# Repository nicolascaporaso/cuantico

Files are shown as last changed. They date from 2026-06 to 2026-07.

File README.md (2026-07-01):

# Cuántico

Cuántico (https://youtu.be/RmWtU8Pogws)

> 🎬 Video de la build: [youtu.be/RmWtU8Pogws](https://youtu.be/RmWtU8Pogws)

Cuántico es un asistente de voz con hardware, personalidad configurable y herramientas reales. Corre en una Raspberry Pi, escucha con wake word, habla por ElevenLabs, razona con OpenRouter y controla luces, música, calendario, YouTube, timers, memoria persistente y audio Bluetooth.

No está pensado para sonar neutro. Está pensado para tener carácter, cambiar de actitud con LEDs y sentirse más criatura de taller que producto pulido.

## Estado actual

- Backend LLM: OpenRouter, no Gemini.
- STT: Deepgram.
- TTS: ElevenLabs.
- Wake word: openWakeWord.
- Salida principal: I2S/VoiceHAT con fallback y soporte para parlantes Bluetooth.
- Personalidad, emociones y luces: perfiles editables en JSON.
- Timers, estado Bluetooth, recuerdos y tokens: persistentes en `state/`.

## Qué hace hoy

- Conversación por voz con wake word.
- Seguimiento sin wake word durante unos segundos después de cada respuesta.
- Búsqueda web integrada para datos actuales.
- Function calling local con tools Python.
- Control de luces Govee: on/off, color y brillo.
- Spotify: canción, playlist por vibe, play/pause, siguiente, anterior, volumen.
- Timers y alarmas persistentes, incluyendo lenguaje natural:
  - `en 30 segundos`
  - `en 5 minutos`
  - `en 2 horas`
  - `mañana a las 7am`
  - `a las 18:30`
- Google Calendar: ver hoy, ver semana, crear eventos.
- YouTube Analytics: métricas y últimos videos.
- Memoria persistente con SQLite.
- Modo llamada por altavoz/micro físico.
- Perfiles de personalidad y reactor LED configurables.
- Audio Bluetooth por voz:
  - buscar
  - listar
  - conectar
  - desconectar
  - consultar cuál está activo
  - volver al altavoz integrado

## Arquitectura

```text
Wake word / VAD / audio
    micro.py
        ↓
Deepgram STT
        ↓
main.py
  - loop principal
  - tools
  - memoria
  - timers
  - modo llamada
        ↓
openrouter_client.py
  - chat
  - tool calling
  - web search
        ↓
altavoz.py
  - ElevenLabs TTS
  - ruta I2S o Bluetooth
        ↓
luces.py
  - reactor LED según estado/emoción
```

Servicios y módulos auxiliares:

- `govee.py`: Developer API v1
- `spotify.py`: Spotify Connect / Raspotify
- `calendario.py`: Google Calendar
- `youtube_stats.py`: YouTube Data + Analytics
- `recuerdos.py`: SQLite
- `timers.py`: scheduler persistente
- `bluetooth_audio.py`: BlueZ + BlueALSA
- `cuantico_profiles.py` + `cuantico_profiles.json`: prompts, emociones y luces

## Hardware

### BOM base

| Componente | Modelo / idea | Notas |
|---|---|---|
| SBC | Raspberry Pi Zero 2 W | La build original apunta a esta. |
| microSD | 16–32 GB clase 10 | Mejor si es decente; Cuántico genera logs y estado persistente. |
| Micrófono | INMP441 I2S | Captura principal. |
| Amplificador | MAX98357A I2S | Salida mono al parlante. |
| Parlante | 3W 4Ω | Conectado al MAX98357A. |
| LEDs | NeoPixel / WS2812B | Reactor visual. |
| Bluetooth | Integrado en la Pi | Para parlantes BT opcionales. |

### Cableado usado en el proyecto

> Los números son pines físicos del header, no BCM.

#### INMP441

| Pin | Pi | Función |
|---|---|---|
| VDD | 1 | 3.3V |
| GND | 39 | GND |
| L/R | a GND | Canal izquierdo |
| SCK | 12 | BCLK |
| WS | 35 | LRCLK |
| SD | 38 | Datos |

#### MAX98357A

| Pin | Pi | Función |
|---|---|---|
| VIN / VDD | 4 | 5V |
| GND | 34 | GND |
| BCLK | 12 | I2S clock |
| LRC | 35 | I2S word select |
| DIN | 40 | Datos hacia el ampli |
| SD | 36 | Mute |

#### NeoPixel

| Pin | Pi |
|---|---|
| 5V | 2 |
| GND | 6 |
| DIN | 32 |

### Carcasa

El repo incluye piezas en `hardware/` para impresión 3D y CNC. Si solo te interesa replicar software, puedes ignorarlo.

## Dependencias del sistema

En Raspberry Pi OS Lite:

```bash
sudo apt update
sudo apt install -y \
  git python3-venv python3-pip \
  sox libsox-fmt-mp3 alsa-utils tmux \
  mpv yt-dlp \
  bluez bluez-alsa-utils
```

Spotify Connect opcional:

```bash
curl -sSL https://dtcooper.github.io/raspotify/install.sh | sh
```

### Overlay de audio recomendado

En `/boot/firmware/config.txt` o `/boot/config.txt`:

```ini
dtparam=i2s=on
dtoverlay=googlevoicehat-soundcard
dtparam=audio=off
```

Reinicia:

```bash
sudo reboot
```

Comprueba:

```bash
arecord -l
aplay -l
```

## Instalación

### 1. Clona el repo

```bash
git clone <tu-repo> ~/cuantico
cd ~/cuantico
```

### 2. Crea el entorno virtual

```bash
python3 -m venv .venv
source .venv/bin/activate
pip install -r requirements.txt
```

### 3. Crea `.env`

```bash
cp .env.example .env
```

### 4. Rellena variables mínimas

Variables imprescindibles para arrancar:

- `OPENROUTER_API_KEY`
- `ELEVENLABS_API_KEY`
- `DEEPGRAM_API_KEY`
- `GOVEE_API_KEY`
- `WAKE_MODEL_PATH`

Variables muy recomendables:

- `CUANTICO_PROFILE`
- `CUANTICO_TIMEZONE`
- `USER_SHORT_NAME`
- `USER_FULL_NAME`

Variables opcionales:

- Spotify
- Google Calendar / YouTube
- Bluetooth
- `OPENROUTER_HTTP_REFERER`

## Variables de entorno

### Identidad y perfil

```env
USER_SHORT_NAME=Nico
USER_FULL_NAME=Nicolas
CUANTICO_PROFILE=argentino
CUANTICO_TIMEZONE=America/Argentina/Buenos_Aires
```

### LLM

```env
OPENROUTER_API_KEY=
OPENROUTER_MODEL=openai/gpt-4o-mini
OPENROUTER_CALL_MODEL=openai/gpt-4o-mini
OPENROUTER_HTTP_REFERER=
```

### Audio

```env
ELEVENLABS_API_KEY=
ELEVENLABS_VOICE_ID=JBFqnCBsd6RMkjVDRZzb
ALSA_PLAYBACK_DEVICE=plughw:0,0
BLUETOOTH_AUTO_ROUTE=true
BLUETOOTH_AUDIO_PROFILE=a2dp
BLUETOOTH_SCAN_SECONDS=8
```

### STT y wake word

```env
DEEPGRAM_API_KEY=
WAKE_MODEL_PATH=/home/nicolas/cuantico/cuantico.onnx
```

También puedes usar un modelo preentrenado de openWakeWord, por ejemplo `hey_jarvis`, si apuntas la ruta correcta dentro de tu entorno.

### Govee

```env
GOVEE_API_KEY=
```

### Spotify

```env
SPOTIFY_CLIENT_ID=
SPOTIFY_CLIENT_SECRET=
SPOTIFY_REDIRECT_URI=http://127.0.0.1:8888/callback
MUSIC_BACKEND_DEFAULT=spotify
YT_DLP_COMMAND=yt-dlp
MPV_COMMAND=mpv
YOUTUBE_AUDIO_SEARCH_LIMIT=5
YOUTUBE_PLAYLIST_SEARCH_LIMIT=8
```

### Google / YouTube

```env
GOOGLE_CLIENT_SECRETS_PATH=state/google_client.json
GOOGLE_TOKEN_PATH=state/google_token.json
YOUTUBE_CHANNEL_ID=
```

## Wake word

Cuántico usa `openwakeword`. En el repo hay un modelo `cuantico.onnx`, pero también puedes usar uno preentrenado o entrenar el tuyo.

Ejemplo:

```env
WAKE_MODEL_PATH=/home/nicolas/cuantico/cuantico.onnx
```

## Primer arranque manual

En la Raspberry:

```bash
sudo .venv/bin/python3 src/main.py
```

> En la Pi el `sudo` es importante por NeoPixel y acceso a hardware. En un entorno sin LEDs físicos no siempre hace falta.

## Spotify

`spotify.py` usa `spotipy` y busca un dispositivo cuyo nombre contenga `raspotify` o `cuantico`.

Flujo real:

- si Spotify no está configurado, se desactiva solo
- si está configurado, intenta descubrir el dispositivo Connect
- si no lo encuentra, deja warning en consola

Primera autorización:

- Spotipy usa flujo OAuth con `open_browser=False`
- en consola te mostrará una URL
- debes abrirla, autorizar y pegar la URL final redirigida

Se guarda en:

- `.spotify_cache`

## Musica Por YouTube

Cuántico también puede reproducir música sin Premium usando:

- `yt-dlp` para buscar y resolver audio
- `mpv` para reproducir y controlar play/pause/siguiente/anterior/volumen

Este backend usa la misma ruta de audio activa que el TTS:

- I2S / VoiceHAT local
- parlante Bluetooth si está conectado y activo

Comportamiento actual:

- antes de arrancar la reproducción, Cuántico prepara el tema y le pide a `mpv` que espere con cache hasta juntar bastante buffer
- para YouTube intenta acercarse a "medio tema" cacheado, con límites razonables para que la espera no se vuelva eterna
- si detecta que esa preparación va a tardar un poco, agrega una frase corta con un dato del tema o del canal mientras termina de cargar
- si la carga pinta rápida, no mete ese comentario extra

Estado persistente:

- `state/music_backend.json`

Variables útiles:

```env
MUSIC_BACKEND_DEFAULT=spotify
YT_DLP_COMMAND=yt-dlp
MPV_COMMAND=mpv
YOUTUBE_AUDIO_SEARCH_LIMIT=5
YOUTUBE_PLAYLIST_SEARCH_LIMIT=8
```

Frases útiles:

- `usá youtube para la música`
- `usá spotify para la música`
- `qué sistema de música estás usando`
- `poné Soda Stereo por youtube`
- `poneme algo chill por youtube`

Notas reales:

- si el backend activo es `youtube`, los comandos generales de música salen por `yt-dlp + mpv`
- si el backend activo es `spotify`, siguen saliendo por Spotify Connect / Raspotify
- cambiar el backend por voz actualiza la preferencia persistente para los próximos pedidos

## Google Calendar y YouTube

`calendario.py` y `youtube_stats.py` comparten el mismo token OAuth.

Primera autorización:

1. Crea un OAuth Client tipo Desktop en Google Cloud.
2. Guarda el JSON como `state/google_client.json`.
3. Ejecuta una vez en una máquina con navegador.
4. Se generará `state/google_token.json`.
5. Copia ese token a la Pi.

Si cambias scopes:

- borra `state/google_token.json`
- vuelve a autorizar

## Timers y alarmas

Cuántico soporta dos tipos:

- timer relativo
- alarma absoluta

Internamente todo se persiste en:

- `state/timers.json`

El scheduler:

- sobrevive a reinicios
- carga timers existentes al arrancar
- dispara callbacks de voz al vencer
- si algo venció mientras estaba apagado, lo levanta al iniciar

Ejemplos de frases soportadas:

- `avisame en 30 segundos`
- `poné una alarma en 5 minutos`
- `avisame en 2 horas`
- `poné una alarma mañana a las 7am`
- `poné una alarma a las 18:30`

## Memoria persistente

La memoria no es historial de chat. Son hechos persistentes.

Se guarda en:

- `state/recuerdos.db`

Sirve para:

- gustos
- personas importantes
- proyectos
- datos estables del usuario

No debería usarse para:

- secretos
- contraseñas
- datos de tarjeta
- cosas efímeras que dejan de ser verdad enseguida

## Audio

### Ruta local

La reproducción local usa:

- `sox` para filtrar/normalizar
- `aplay` para sacar el audio
- GPIO16 para mutear/desmutear el ampli de la VoiceHAT

### Sonido de arranque

Si existe `test.wav` en la raíz del repo, Cuántico puede reproducirlo al arrancar.

### Bluetooth

El control Bluetooth está en `src/bluetooth_audio.py` y usa:

- `bluetoothctl`
- BlueZ
- BlueALSA

Estado persistente:

- `state/bluetooth_audio.json`

Funciones soportadas:

- buscar dispositivos
- listar dispositivos
- conectar uno por nombre o MAC
- desconectar uno concreto
- consultar cuál está activo
- volver al altavoz integrado
- recordar el parlante Bluetooth preferido

Frases útiles:

- `buscá parlantes bluetooth`
- `listá los parlantes bluetooth`
- `conectá el JBL Flip`
- `desconectá el JBL Flip`
- `qué parlante bluetooth está conectado`
- `volvé al altavoz integrado`

Si el parlante BT no está conectado en el momento de hablar:

- Cuántico vuelve al `ALSA_PLAYBACK_DEVICE` local

## Reactor LED y emociones

`luces.py` no tiene efectos fijos hardcodeados por personalidad. El reactor se alimenta desde `cuantico_profiles.json`.

Estados base del sistema:

- `esperando`
- `escuchando`
- `pensando`
- `apagado`

Estados emocionales:

- dependen del perfil activo
- se detectan por triggers en la respuesta de Cuántico
- controlan color, patrón y velocidad

Efectos soportados:

- `pulse`
- `spinner`
- `flicker`
- `rainbow`
- `blink`
- `alternate`
- `off`

## Perfiles, prompts y personalidad

Los prompts ya no viven en `main.py`. Viven en:

- `src/cuantico_profiles.json`
- `src/cuantico_profiles.py`

Un perfil define:

- `label`
- `main_prompt`
- `call_prompt`
- `default_emotion`
- `emotion_rules`
- `light_states`
- alias de estados si hace falta

Perfiles incluidos hoy:

- `argentino`
- `espanol`
- `tanguero`

Selección:

```env
CUANTICO_PROFILE=tanguero
```

Para crear uno nuevo:

1. Duplica un perfil en `src/cuantico_profiles.json`
2. Ponle una nueva clave
3. Cambia `CUANTICO_PROFILE`
4. Reinicia Cuántico

## Modo llamada

`llamada.py` monta un modo especial para hablar con otra persona por teléfono usando el móvil en altavoz al lado del dispositivo.

Flujo:

1. El usuario activa la intención de llamada.
2. Cuántico responde normal.
3. Al terminar de hablar entra en modo llamada.
4. Usa un prompt específico, más profesional.
5. Escucha y responde por streaming.
6. Sale por:
   - marcador `[FIN_LLAMADA]`
   - silencio largo
   - timeout global
   - orden explícita de colgar

## Servicio systemd

El repo incluye:

- `cuantico.service`

Instalación:

```bash
sudo cp ~/cuantico/cuantico.service /etc/systemd/system/cuantico.service
sudo systemctl daemon-reload
sudo systemctl enable --now cuantico
```

Comandos útiles:

```bash
systemctl status cuantico
journalctl -u cuantico -f
sudo systemctl restart cuantico
sudo systemctl stop cuantico
```

El servicio actual:

- arranca tras red, sonido y Bluetooth
- corre como `root`
- usa `/home/nicolas/cuantico` como ejemplo de ruta

Ajústalo si tu usuario o ruta son distintos.

## Logs y depuración

Además de `journalctl`, Cuántico escribe trazas estructuradas en:

- `state/unexpected-process-exit.log`

Se instrumentan, entre otras cosas:

- arranque y cierre
- excepciones no manejadas
- excepciones de threads
- señales
- wake word
- Deepgram
- OpenRouter
- TTS
- timers
- callbacks de alarma
- Bluetooth

Archivos de ayuda incluidos:

- `debug-unexpected-process-exit.md`
- `debug-timer-alarm-exit.md`

## Estado persistente generado

Durante el uso se crean o actualizan estos archivos:

- `state/recuerdos.db`
- `state/timers.json`
- `state/bluetooth_audio.json`
- `state/music_backend.json`
- `state/google_client.json`
- `state/google_token.json`
- `state/unexpected-process-exit.log`

Y también:

- `.spotify_cache`

## Estructura del repo

```text
.
├── README.md
├── LICENSE
├── requirements.txt
├── .env.example
├── cuantico.service
├── cuantico.onnx
├── cuantico.onnx.data
├── debug-timer-alarm-exit.md
├── debug-unexpected-process-exit.md
├── hardware/
└── src/
    ├── altavoz.py
    ├── bluetooth_audio.py
    ├── calendario.py
    ├── config.py
    ├── cuantico_profiles.json
    ├── cuantico_profiles.py
    ├── govee.py
    ├── llamada.py
    ├── luces.py
    ├── main.py
    ├── music_router.py
    ├── music_youtube.py
    ├── micro.py
    ├── openrouter_client.py
    ├── recuerdos.py
    ├── spotify.py
    ├── timers.py
    └── youtube_stats.py
```

## Troubleshooting

### No suena la voz pero `test.wav` sí

Te falta casi seguro:

```bash
sudo apt install -y libsox-fmt-mp3
```

### El micro no abre a 16 kHz

Es normal en algunos devices I2S/VoiceHAT. `micro.py` ya hace fallback a 48 kHz y remuestrea a 16 kHz.

### Spotify no aparece

- verifica que `raspotify` esté corriendo
- revisa el nombre del dispositivo Connect
- ajusta `DEVICE_HINTS` en `src/spotify.py` si hace falta

### YouTube no reproduce musica

- instala `mpv` y `yt-dlp`
- revisa que `YT_DLP_COMMAND` y `MPV_COMMAND` apunten a binarios válidos
- si usás Bluetooth, verifica que `state/bluetooth_audio.json` apunte al parlante correcto
- si `spotify` te da `403`, cambia temporalmente el backend con `usá youtube para la música`

### Govee da 401 o no controla nada

- revisa tu API key
- no todos los modelos sirven con la Developer API v1

### Wake word responde mal

Revisa en `src/micro.py`:

- `WAKE_THRESHOLD`
- `GANANCIA_MIC`

Y mira los logs `score wake=...`.

### Se cayó la Pi o perdió SSH

Cuando vuelva:

```bash
journalctl -b -1 -n 200 --no-pager
journalctl -k -b -1 -n 200 --no-pager
dmesg -T | tail -n 120
```

### La base SQLite quedó readonly

Si corriste Cuántico con `sudo`, puede que `state/` quede propiedad de `root`.

Corrígelo si quieres inspeccionarla manualmente:

```bash
sudo chown -R nicolas:nicolas state
```

### Bluetooth no conecta

Comprueba:

```bash
sudo systemctl status bluetooth
bluetoothctl devices
bluetoothctl info <MAC>
```

Y asegúrate de tener:

```bash
sudo apt install -y bluez bluez-alsa-utils
```

## Stack

- LLM gateway: [OpenRouter](https://openrouter.ai/)
- STT: [Deepgram](https://deepgram.com/)
- TTS: [ElevenLabs](https://elevenlabs.io/)
- Wake word: [openWakeWord](https://github.com/dscripka/openWakeWord)
- VAD: [webrtcvad](https://github.com/wiseman/py-webrtcvad)
- Spotify: [spotipy](https://spotipy.readthedocs.io/)
- Google APIs: Calendar + YouTube
- LEDs: NeoPixel / `rpi_ws281x`

## Licencia

Ver `LICENSE`.

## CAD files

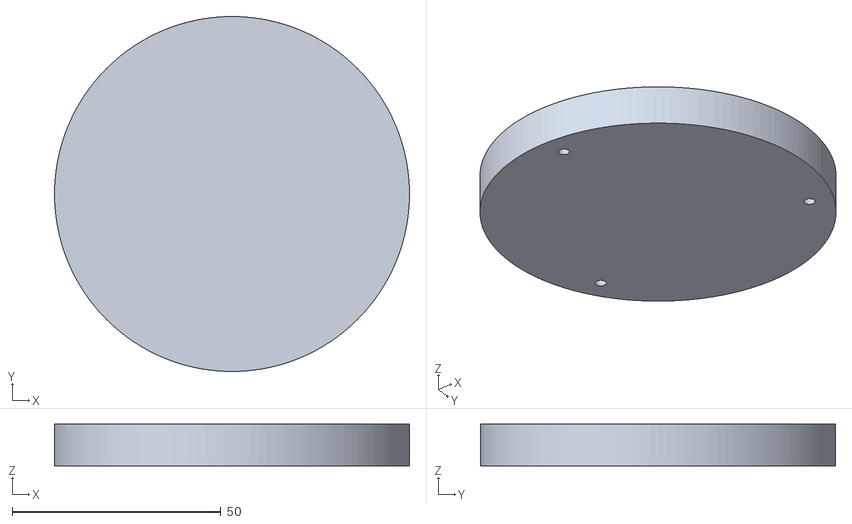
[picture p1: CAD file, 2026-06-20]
hardware/3d printing/Tapa_Cuantico.stl
85.0 x 85.0 x 10.0

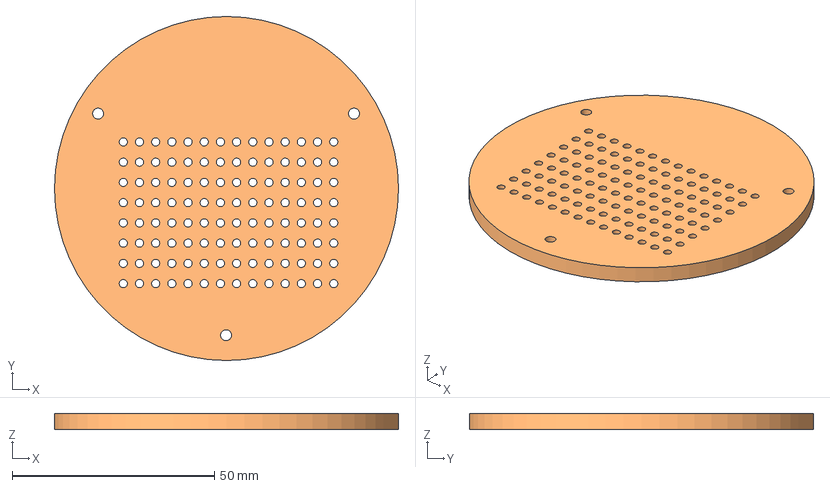
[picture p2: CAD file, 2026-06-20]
hardware/CNC/Intermedio.stp
85.0 x 85.0 x 4.00 mm

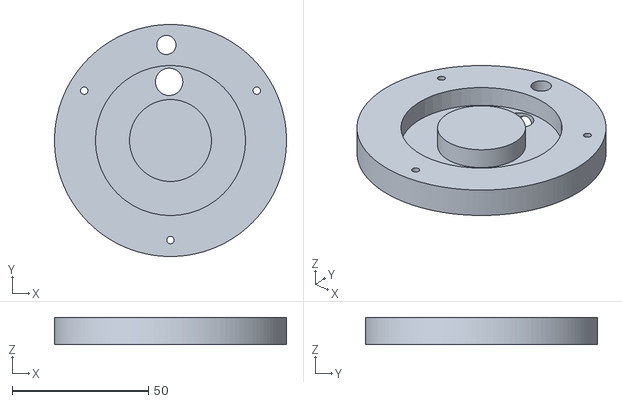
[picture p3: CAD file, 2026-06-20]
hardware/3d printing/Base_Cuantico.stl
85.0 x 85.0 x 10.00

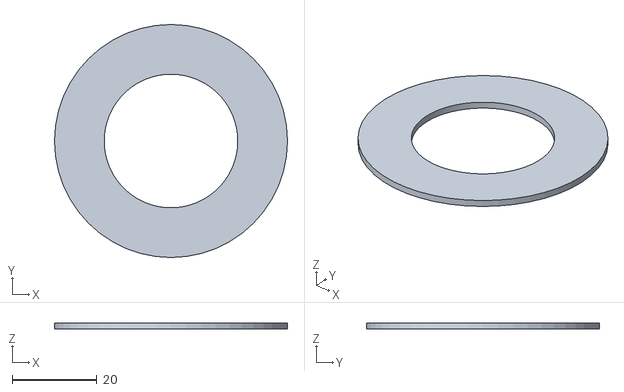
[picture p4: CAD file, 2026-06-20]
hardware/3d printing/Luces_Tapa.stl
55.0 x 55.0 x 1.50

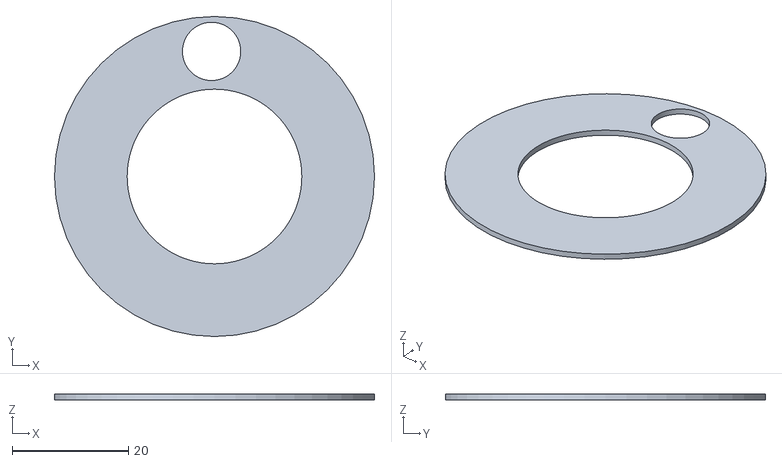
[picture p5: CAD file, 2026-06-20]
hardware/3d printing/Luces_Base.stl
55.0 x 55.0 x 1.00

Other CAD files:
hardware/CNC/Tapa.stp
hardware/CNC/Base.stp
hardware/3d printing/Intermedio_Cuantico.stl

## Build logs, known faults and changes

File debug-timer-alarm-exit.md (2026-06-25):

[OPEN] timer-alarm-exit

## Objetivo
- Corregir el manejo de timers/alarmas relativas y absolutas.
- Ajustar la zona horaria interna a America/Argentina/Buenos_Aires.
- Agregar logs y manejo de excepciones alrededor del scheduler/callback para capturar fallas reales cuando vence una alarma.

## Sintomas
- Pedidos como "en 60 segundos" a veces terminan yendo por `crear_alarma_hora`.
- La hora interna de referencia sigue orientada a Europe/Madrid.
- El usuario reporta cierre del proceso cuando una alarma vence y habla.

## Hipotesis
1. El modelo elige la tool equivocada por docstrings/prompt insuficientemente precisos para diferenciar duracion relativa vs hora absoluta.
2. El scheduler dispara bien, pero el callback de alarma rompe el proceso durante `_hablar()` o TTS.
3. La zona horaria usada por Cuantico deforma la interpretacion de horas y empeora la seleccion de tools.
4. `timers.py` carece de instrumentacion suficiente y por eso el error real del callback queda oculto.
5. La configuracion del servicio systemd no es la causa principal, aunque tiene un warning aparte.

## Evidencia Actual
- Logs muestran que "Poné una alarma para dentro de 60 segundos" llamo `crear_alarma_hora("02:34")` en vez de `crear_temporizador(...)`.
- `timers.py` programa alarmas HH:MM para hoy o manana si ya paso.
- No hay aun evidencia completa del cierre al vencer una alarma porque faltan logs explicitos en `timers.py`.

## Instrumentacion Aplicada
- `timers.py` ahora emite:
  - `timers-init`
  - `timer-created`
  - `alarm-created`
  - `timer-fired`
  - `timer-callback-start`
  - `timer-callback-end`
  - `timer-callback-error`
- `main.py` ahora emite:
  - `alarm-callback-enter`
  - `alarm-callback-exit`
  - `alarm-callback-error`

## Fix Aplicado
1. Se agrego `programar_aviso(cuando, etiqueta)` como tool unificada para lenguaje natural:
   - segundos
   - minutos
   - horas
   - dias
   - hoy/manana a HH:MM
   - am/pm
2. Se reforzaron docstrings y prompt para preferir esa tool en pedidos temporales.
3. La zona horaria interna se cambio a `America/Argentina/Buenos_Aires`.
4. `timers.py` ahora calcula alarmas absolutas con hora local de Buenos Aires.
5. `calendario.py`, `recuerdos.py` y referencias temporales del prompt usan la nueva zona horaria.
6. `cuantico.service` se corrigio para usar la ruta real y mover `StartLimitIntervalSec/StartLimitBurst` a `[Unit]`.

## Plan
1. Instrumentar `timers.py` y el callback de alarma con logs y excepciones controladas.
2. Verificar como se construye el contexto temporal del modelo.
3. Implementar soporte robusto para segundos/minutos/horas relativos y horas absolutas.
4. Ajustar zona horaria de referencia a Buenos Aires.
5. Validar con compilacion y dejar guia de prueba.

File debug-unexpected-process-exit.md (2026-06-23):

[OPEN] Debug Session: unexpected-process-exit

## Resumen
- Sintoma: Cuantico "se cuelga", pero en realidad el proceso Python se cierra mientras la Raspberry sigue encendida.
- Objetivo: recolectar evidencia de runtime para identificar por que el proceso termina.

## Hipotesis Iniciales
1. Una excepcion no capturada fuera del loop principal termina el proceso.
2. Un subproceso de audio/TTS/STT falla y arrastra el cierre del proceso.
3. Un fallo de red o I/O queda oculto y dispara una salida fatal.
4. Un hilo secundario (luces, timers, micro) lanza una excepcion relevante.
5. Existe una ruta de salida no intencional en el flujo principal.

## Plan
1. Agregar instrumentacion de arranque, ciclo principal y cierres.
2. Agregar trazas en puntos criticos: audio, micro, timers, modo llamada, OpenRouter.
3. Reproducir la caida y observar el ultimo bloque de logs.
4. Confirmar o descartar hipotesis con evidencia.
5. Aplicar fix minimo cuando la causa este probada.

## Evidencia Recolectada
- Hipotesis 1 confirmada.
- La wake word se detecto correctamente (`score` 0.445 / 0.886), pero el proceso cayo antes de pasar a reconocimiento de voz.
- La excepcion exacta fue:
  - `TypeError: Object of type float32 is not JSON serializable`
  - origen: `micro.py` en `_debug_emit("wake-detected", {"score": round(mejor, 4), ...})`
- El cierre no vino del flujo de negocio sino del logger de instrumentacion.

## Fix Minimo Aplicado
1. Se agrego serializacion segura para tipos numpy en `micro.py`.
2. Se fuerza `score` y `threshold` a `float` nativo al registrar `wake-detected`.

## Estado
- Listo para reintentar reproduccion con la misma instrumentacion.

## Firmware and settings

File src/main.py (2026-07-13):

import time
import threading
import traceback
import sys
import os
import json
import urllib.request
import signal
import atexit
from datetime import datetime, timedelta
from pathlib import Path
import config
import luces
import micro
import altavoz
import bluetooth_audio
import govee
import music_router
import spotify
import timers
import wiz_controller
from devices import tv as tv_devices
import button_controller
import calendario
import youtube_stats
import llamada
import recuerdos
import cuantico_profiles as profile
from openrouter_client import OpenRouterChatSession

USER_SHORT_NAME = config.USER_SHORT_NAME
USER_FULL_NAME = config.USER_FULL_NAME
ACTIVE_PROFILE_NAME = profile.get_active_profile_name()
_accion_sistema_pendiente: str | None = None
_force_new_conversation = False
_button_state_lock = threading.RLock()
_button_conversation_requested = False
_button_conversation_active = False
_button_pause_active = False
_button_resume_pending_until = 0.0
_button_conversation_mode = ""
_radar_enabled = True
_active_listening_context = ""
_listening_cancel_requested = False


class _RestartRequested(Exception):
    pass


# #region debug-point A:runtime-hooks
_DEBUG_ENV_PATH = Path(__file__).resolve().parent.parent / ".dbg" / "unexpected-process-exit.env"
_DEBUG_LOG_PATH = Path(config.STATE_DIR) / "unexpected-process-exit.log"


def _debug_emit(hypothesis_id: str, msg: str, data: dict | None = None):
    payload = {
        "sessionId": "unexpected-process-exit",
        "runId": "pre-fix",
        "hypothesisId": hypothesis_id,
        "location": "main.py",
        "msg": f"[DEBUG] {msg}",
        "data": data or {},
        "ts": int(time.time() * 1000),
    }
    line = json.dumps(payload, ensure_ascii=False)
    try:
        print(line, flush=True)
    except Exception:
        pass
    try:
        with open(_DEBUG_LOG_PATH, "a", encoding="utf-8") as f:
            f.write(line + "\n")
    except Exception:
        pass
    try:
        debug_url = "http://127.0.0.1:7777/event"
        if _DEBUG_ENV_PATH.exists():
            for env_line in _DEBUG_ENV_PATH.read_text(encoding="utf-8").splitlines():
                if env_line.startswith("DEBUG_SERVER_URL="):
                    debug_url = env_line.split("=", 1)[1].strip()
        req = urllib.request.Request(
            debug_url,
            data=line.encode("utf-8"),
            headers={"Content-Type": "application/json"},
        )
        urllib.request.urlopen(req, timeout=0.8).read()
    except Exception:
        pass


def _debug_excepthook(exc_type, exc, tb):
    _debug_emit("A", "unhandled-exception", {"type": getattr(exc_type, "__name__", str(exc_type)), "error": str(exc), "traceback": "".join(traceback.format_exception(exc_type, exc, tb))})
    sys.__excepthook__(exc_type, exc, tb)


def _debug_threading_excepthook(args):
    _debug_emit("D", "thread-exception", {"thread": getattr(args.thread, "name", "unknown"), "type": getattr(args.exc_type, "__name__", str(args.exc_type)), "error": str(args.exc_value), "traceback": "".join(traceback.format_exception(args.exc_type, args.exc_value, args.exc_traceback))})
    if threading.__excepthook__:
        threading.__excepthook__(args)


def _debug_signal_handler(signum, _frame):
    _debug_emit("A", "signal-received", {"signal": signum})
    raise KeyboardInterrupt


_DEBUG_LOG_PATH.parent.mkdir(exist_ok=True)
_fault_log = open(_DEBUG_LOG_PATH, "a", encoding="utf-8")
sys.excepthook = _debug_excepthook
threading.excepthook = _debug_threading_excepthook
signal.signal(signal.SIGTERM, _debug_signal_handler)
signal.signal(signal.SIGINT, _debug_signal_handler)
try:
    import faulthandler
    faulthandler.enable(_fault_log)
except Exception as _debug_fh_error:
    _debug_emit("A", "faulthandler-enable-failed", {"error": str(_debug_fh_error)})
atexit.register(lambda: _debug_emit("A", "process-exit", {"timestamp": config.now_local().isoformat()}))
_debug_emit("A", "module-loaded", {"user_short_name": USER_SHORT_NAME, "user_full_name": USER_FULL_NAME, "profile": ACTIVE_PROFILE_NAME})
# #endregion


SYSTEM_PROMPT = profile.render_main_prompt()


# ---------- TOOLS ----------

def encender_luces_casa(luz: str = "") -> str:
    """Enciende luces de la casa. Si el nombre coincide con una WiZ registrada (ej. velador), enrútala a WiZ; si no, usa Govee.

    Args:
        luz: (opcional) Nombre de la luz concreta a encender (ej: 'Esfera'). Déjalo vacío para encender TODAS las luces.
    """
    sistema = _resolver_sistema_luz(luz=luz) if luz else "govee"
    if sistema == "wiz":
        try:
            return "ok" if wiz_controller.encender(luz) else "fallo: esa luz WiZ no existe o no responde"
        except Exception as e:
            return f"fallo: {e}"
    return "ok" if govee.encender_todas(luz or None) else "fallo: esa luz no existe o no responde (wifi caído?)"

def apagar_luces_casa(luz: str = "") -> str:
    """Apaga luces de la casa. Si el nombre coincide con una WiZ registrada (ej. velador), enrútala a WiZ; si no, usa Govee.

    Args:
        luz: (opcional) Nombre de la luz concreta a apagar. Déjalo vacío para apagar TODAS.
    """
    sistema = _resolver_sistema_luz(luz=luz) if luz else "govee"
    if sistema == "wiz":
        try:
            return "ok" if wiz_controller.apagar(luz) else "fallo: no pude apagar esa luz WiZ"
        except Exception as e:
            return f"fallo: {e}"
    return "ok" if govee.apagar_todas(luz or None) else "fallo: esa luz no existe o no responde (wifi caído?)"

def cambiar_color_luces(r: int, g: int, b: int, luz: str = "") -> str:
    """Cambia el color de las luces de la casa. Si el nombre coincide con una WiZ registrada (ej. velador), enrútala a WiZ; si no, usa Govee. Tú traduces el color/ambiente que pide nico a RGB. Ejemplos: rojo=255,0,0; azul=0,0,255; azul cielo=135,206,235; blanco cálido=255,180,120; morado=160,32,240; verde lima=50,205,50; naranja atardecer=255,140,0; rosa pastel=255,182,193; rojo romántico=180,0,30. Para ambientes ("modo fiesta", "modo peli de terror", "gaming"), elige un color que encaje.

    Args:
        r: Componente rojo (0-255).
        g: Componente verde (0-255).
        b: Componente azul (0-255).
        luz: (opcional) Nombre de la luz concreta (ej: 'Esfera'). Déjalo vacío para todas.
    """
    sistema = _resolver_sistema_luz(luz=luz) if luz else "govee"
    if sistema == "wiz":
        try:
            return "ok" if wiz_controller.cambiar_color(r, g, b, luz, brillo=100) else "fallo: no pude cambiar el color WiZ"
        except Exception as e:
            return f"fallo: {e}"
    return "ok" if govee.cambiar_color_todas(r, g, b, luz or None) else "fallo: esa luz no existe o no soporta color"

def cambiar_brillo_luces(porcentaje: int, luz: str = "") -> str:
    """Ajusta el brillo de las luces de la casa. Si el nombre coincide con una WiZ registrada (ej. velador), enrútala a WiZ; si no, usa Govee. Útil cuando nico dice 'baja las luces', 'sube la intensidad', 'modo lectura' (brillo alto), 'ambiente romántico' (brillo bajo).

    Args:
        porcentaje: Brillo de 1 (casi apagado) a 100 (máximo). Nunca 0 — para apagar usa apagar_luces_casa.
        luz: (opcional) Nombre de la luz concreta. Déjalo vacío para todas.
    """
    sistema = _resolver_sistema_luz(luz=luz) if luz else "govee"
    if sistema == "wiz":
        try:
            return "ok" if wiz_controller.fijar_brillo(porcentaje, luz) else "fallo: no pude ajustar el brillo WiZ"
        except Exception as e:
            return f"fallo: {e}"
    return "ok" if govee.cambiar_brillo_todas(porcentaje, luz or None) else "fallo: esa luz no existe o no acepta brillo"


def buscar_luces_wiz() -> str:
    """Busca luces WiZ disponibles por red local usando pywizlight. Úsala cuando nico pida escanear, buscar o descubrir luces WiZ nuevas."""
    try:
        luces_wiz = wiz_controller.buscar_luces()
    except Exception as e:
        return f"fallo: {e}"
    if not luces_wiz:
        return "no encontré luces WiZ en la red"
    return "; ".join(
        f"{item['name']} ({item['ip']})"
        + (f", mac {item['mac']}" if item.get("mac") else "")
        + (" ya registrada" if item.get("known") else " nueva")
        + (" con IP actualizada" if item.get("ip_changed") else "")
        for item in luces_wiz
    )


def agregar_luz_wiz(ip_o_selector: str, nombre: str = "") -> str:
    """Agrega una luz WiZ al registro persistente por IP o por una luz recién descubierta. Úsala cuando nico diga que la agregues, la guardes o la registres.

    Args:
        ip_o_selector: IP o texto que identifique la luz recién descubierta.
        nombre: Nombre amigable opcional. Ej: 'Dormitorio', 'Velador', 'Escritorio'.
    """
    try:
        info = wiz_controller.agregar_luz(ip_o_selector, nombre)
        return f"ok: luz WiZ registrada como {info['name']} ({info['ip']})"
    except Exception as e:
        return f"fallo: {e}"


def renombrar_luz_wiz(luz: str, nombre_nuevo: str) -> str:
    """Renombra una luz WiZ ya registrada. Úsala cuando nico diga 'esa luz del dormitorio ahora llamala velador' o quiera poner nombres más cómodos.

    Args:
        luz: Nombre actual o IP de la luz.
        nombre_nuevo: Nuevo nombre amigable.
    """
    try:
        info = wiz_controller.renombrar_luz(luz, nombre_nuevo)
        return f"ok: ahora la luz WiZ {info['ip']} se llama {info['name']}"
    except Exception as e:
        return f"fallo: {e}"


def listar_luces_wiz() -> str:
    """Lista las luces WiZ registradas, cuántas están online y si está activo el modo de copiar emociones. Úsala cuando nico pregunte qué luces WiZ hay, cómo se llaman, cuántas tiene registradas, cuántas están online o si quedó activo el sync emocional."""
    try:
        return wiz_controller.resumen_estado()
    except Exception as e:
        return f"fallo: {e}"


def contar_luces_wiz() -> str:
    """Resume cuántas luces WiZ hay registradas, cuántas están online y cuántas offline. Úsala para preguntas como 'cuántas luces WiZ tengo', 'cuántas están online' o 'decime el estado de mis WiZ'."""
    try:
        info = wiz_controller.contar_luces()
    except Exception as e:
        return f"fallo: {e}"
    base = (
        f"WiZ registradas: {info['registered']}. "
        f"Online: {info['online']}. "
        f"Offline: {info['offline']}."
    )
    if info.get("discovery_error"):
        base += f" No pude refrescar discovery ahora: {info['discovery_error']}"
    return base


def eliminar_luz_wiz(luz: str) -> str:
    """Elimina una luz WiZ registrada por nombre, IP o MAC. Úsala cuando nico pida borrar, quitar, eliminar u olvidar una luz vieja del registro."""
    try:
        info = wiz_controller.eliminar_luz(luz)
        return f"ok: eliminé la luz WiZ {info['name']} ({info['ip']})"
    except Exception as e:
        return f"fallo: {e}"


def encender_luces_wiz(luz: str = "") -> str:
    """Enciende luces WiZ registradas. Úsala cuando nico diga que prenda una luz WiZ concreta o todas las WiZ.

    Args:
        luz: Nombre o IP de la luz WiZ. Déjalo vacío para todas las registradas.
    """
    try:
        return "ok" if wiz_controller.encender(luz) else "fallo: no pude encender esas luces WiZ"
    except Exception as e:
        return f"fallo: {e}"


def apagar_luces_wiz(luz: str = "") -> str:
    """Apaga luces WiZ registradas. Úsala cuando nico pida apagar una luz WiZ concreta o todas.

    Args:
        luz: Nombre o IP de la luz WiZ. Déjalo vacío para todas.
    """
    try:
        return "ok" if wiz_controller.apagar(luz) else "fallo: no pude apagar esas luces WiZ"
    except Exception as e:
        return f"fallo: {e}"


def cambiar_color_luces_wiz(r: int, g: int, b: int, luz: str = "", brillo: int = 100) -> str:
    """Pone una luz WiZ en un color RGB concreto. Úsala para pedidos como 'pone la luz Wiz del dormitorio en verde', 'roja', 'azul', 'violeta' o para copiar una emoción en un color.

    Args:
        r: Componente rojo 0-255.
        g: Componente verde 0-255.
        b: Componente azul 0-255.
        luz: Nombre o IP de la luz WiZ. Déjalo vacío para todas.
        brillo: Brillo 1-100.
    """
    try:
        return "ok" if wiz_controller.cambiar_color(r, g, b, luz, brillo=brillo) else "fallo: no pude cambiar el color WiZ"
    except Exception as e:
        return f"fallo: {e}"


def fijar_brillo_luces_wiz(porcentaje: int, luz: str = "") -> str:
    """Fija el brillo de una luz WiZ a un valor exacto. Úsala para frases como 'pone la luz Wiz al 70%' o 'dejala suave al 30%'.

    Args:
        porcentaje: Brillo 1-100.
        luz: Nombre o IP de la luz WiZ. Déjalo vacío para todas.
    """
    try:
        return "ok" if wiz_controller.fijar_brillo(porcentaje, luz) else "fallo: no pude ajustar el brillo WiZ"
    except Exception as e:
        return f"fallo: {e}"


def ajustar_brillo_luces_wiz(delta: int, luz: str = "") -> str:
    """Sube o baja el brillo de una luz WiZ respecto al valor actual. Úsala para pedidos como 'subí la luz 20%' o 'bajala 15%'.

    Args:
        delta: Cambio relativo. Ej: +20 o -15.
        luz: Nombre o IP de la luz WiZ. Déjalo vacío para todas.
    """
    try:
        return "ok" if wiz_controller.ajustar_brillo(delta, luz) else "fallo: no pude mover el brillo WiZ"
    except Exception as e:
        return f"fallo: {e}"


def poner_luz_lectura_wiz(luz: str = "") -> str:
    """Pone una luz WiZ en modo lectura: blanca neutra y con brillo cómodo para leer o trabajar.

    Args:
        luz: Nombre o IP de la luz WiZ. Déjalo vacío para todas.
    """
    try:
        return "ok" if wiz_controller.modo_lectura(luz) else "fallo: no pude poner la luz de lectura WiZ"
    except Exception as e:
        return f"fallo: {e}"


def parpadear_luces_wiz(segundos: int = 30, luz: str = "") -> str:
    """Hace parpadear luces WiZ durante unos segundos. Úsala para pedidos como 'hacé parpadear la luz del dormitorio 30 segundos'.

    Args:
        segundos: Duración del parpadeo.
        luz: Nombre o IP de la luz WiZ. Déjalo vacío para todas.
    """
    try:
        return "ok" if wiz_controller.parpadear(luz, segundos) else "fallo: no pude lanzar ese parpadeo WiZ"
    except Exception as e:
        return f"fallo: {e}"


def efecto_luces_wiz(efecto: str = "fiesta", luz: str = "", segundos: int = 30) -> str:
    """Lanza un efecto temporal en luces WiZ. Úsala para pedidos como 'hacé efecto de luces', 'modo fiesta', 'arcoiris', 'policía' o 'respirar'.

    Args:
        efecto: Nombre del efecto. Recomendados: 'fiesta', 'arcoiris', 'policia', 'respirar', 'parpadeo'.
        luz: Nombre o IP de la luz WiZ. Déjalo vacío para todas.
        segundos: Duración del efecto. Usa 0 si querés que quede corriendo hasta otro cambio.
    """
    try:
        return "ok" if wiz_controller.efecto(efecto, luz, segundos) else "fallo: no pude arrancar ese efecto WiZ"
    except Exception as e:
        return f"fallo: {e}"


def copiar_emocion_a_luz_wiz(luz: str = "") -> str:
    """Activa el modo donde Cuántico copia sus emociones y estados al color/efecto de las luces WiZ. Úsala cuando nico diga 'copiá tus emociones a la luz Wiz' o 'sincronizate con la luz del dormitorio'.

    Args:
        luz: Nombre o IP de la luz WiZ que debe seguir las emociones. Déjalo vacío para todas las WiZ registradas.
    """
    try:
        wiz_controller.activar_sync_emociones(luz)
        wiz_controller.sincronizar_estado_si_activo("esperando")
        if luz:
            return f"ok: las emociones de Cuántico ahora se copian a la luz WiZ {luz}"
        return "ok: las emociones de Cuántico ahora se copian a todas las luces WiZ"
    except Exception as e:
        return f"fallo: {e}"


def desactivar_copia_emocion_wiz() -> str:
    """Desactiva el modo de copiar emociones de Cuántico a las luces WiZ."""
    try:
        return "ok" if wiz_controller.desactivar_sync_emociones() else "fallo: no pude apagar el sync emocional WiZ"
    except Exception as e:
        return f"fallo: {e}"


def estado_luces_wiz(luz: str = "") -> str:
    """Dice el estado actual de las luces WiZ: encendida, brillo, escena o color conocido. Úsala cuando nico pregunte cómo quedó una luz WiZ o si está prendida.

    Args:
        luz: Nombre o IP de la luz WiZ. Déjalo vacío para todas.
    """
    try:
        estados = wiz_controller.estado_actual(luz)
    except Exception as e:
        return f"fallo: {e}"
    partes = []
    for estado in estados:
        if estado["is_on"]:
            detalle = f"encendida al {estado['brightness']}%"
            if estado.get("scene"):
                detalle += f", escena {estado['scene']}"
            elif estado.get("rgb"):
                detalle += f", rgb {tuple(estado['rgb'])}"
            elif estado.get("colortemp"):
                detalle += f", {estado['colortemp']}K"
        else:
            detalle = "apagada"
        partes.append(f"{estado['name']} ({estado['ip']}): {detalle}")
    return "; ".join(partes)


def _tv_result_text(resultado, ok_default: str = "ok") -> str:
    if resultado is None:
        return "fallo: sin respuesta del controlador de TV"
    if getattr(resultado, "ok", False):
        return resultado.message or ok_default
    return f"fallo: {resultado.message or 'error desconocido'}"


def buscar_tvs() -> str:
    """Busca televisores compatibles en la red local. Úsala cuando nico pida escanear, descubrir o buscar TVs Samsung/Tizen nuevas."""
    resultado = tv_devices.discover()
    if not resultado.ok:
        return f"{_tv_result_text(resultado)}. Si ya sabés la IP, probá vincularla directo."
    devices = resultado.data.get("devices") or []
    return "; ".join(
        f"{item.get('name') or 'TV'} ({item.get('brand')}, {item.get('host')})"
        + (f", modelo {item.get('model')}" if item.get("model") else "")
        + (f", mac {item.get('mac')}" if item.get("mac") else "")
        for item in devices
    ) or "ok: no encontré TVs nuevas"


def vincular_tv(selector: str, nombre: str = "") -> str:
    """Vincula un televisor descubierto para reutilizarlo después y guardar su token. Úsala cuando nico diga que agregues, registres o vincules un TV.

    Args:
        selector: Nombre, IP o MAC del TV descubierto.
        nombre: Nombre amigable opcional. Ej: 'Tele del living'.
    """
    resultado = tv_devices.bind_device(selector, nombre)
    if not resultado.ok:
        return _tv_result_text(resultado)
    device = (resultado.data or {}).get("device") or {}
    return f"ok: TV vinculado como {device.get('name') or selector} ({device.get('host', '')})"


def listar_tvs() -> str:
    """Lista los TVs registrados y cuántos aparecen online. Úsala cuando nico pregunte qué televisor tiene, cuántos hay o cuál está disponible."""
    resultado = tv_devices.list_devices(refresh=False)
    if not resultado.ok:
        return _tv_result_text(resultado)
    devices = resultado.data.get("devices") or []
    if not devices:
        return "no tengo TVs registrados todavía"
    return "; ".join(
        f"{item.get('name') or 'TV'} ({item.get('brand')}, {item.get('host')})"
        + (" online" if item.get("connected") else " offline")
        + (" por defecto" if item.get("device_id") == resultado.data.get("default_device_id") else "")
        for item in devices
    )


def olvidar_tv(selector: str) -> str:
    """Elimina un televisor del registro y borra el vínculo guardado. Úsala cuando nico pida quitar, borrar u olvidar un TV viejo."""
    return _tv_result_text(tv_devices.forget_device(selector))


def estado_tv(tv: str = "") -> str:
    """Consulta el estado de un televisor registrado. Úsala cuando nico pregunte si el TV está online, cuál es o cómo quedó.

    Args:
        tv: Nombre, IP o MAC del TV. Déjalo vacío para usar el TV por defecto.
    """
    resultado = tv_devices.get_status(tv)
    if not resultado.ok:
        return _tv_result_text(resultado)
    device = (resultado.data or {}).get("device") or {}
    return (
        f"TV {device.get('name') or device.get('host')}: online. "
        f"IP {device.get('host', '')}. "
        f"Modelo {device.get('model') or 'desconocido'}."
    )


def encender_tv(tv: str = "") -> str:
    """Enciende un televisor registrado. Úsala cuando nico pida prender el tele, la tele del living o el Samsung.

    Args:
        tv: Nombre, IP o MAC del TV. Déjalo vacío para el TV por defecto.
    """
    return _tv_result_text(tv_devices.power_on(tv))


def apagar_tv(tv: str = "") -> str:
    """Apaga un televisor registrado.

    Args:
        tv: Nombre, IP o MAC del TV. Déjalo vacío para el TV por defecto.
    """
    return _tv_result_text(tv_devices.power_off(tv))


def subir_volumen_tv(tv: str = "") -> str:
    """Sube el volumen del televisor registrado."""
    return _tv_result_text(tv_devices.volume_up(tv))


def bajar_volumen_tv(tv: str = "") -> str:
    """Baja el volumen del televisor registrado."""
    return _tv_result_text(tv_devices.volume_down(tv))


def fijar_volumen_tv(nivel: int, tv: str = "") -> str:
    """Intenta fijar el volumen del TV en un valor concreto.

    Args:
        nivel: Volumen objetivo de 0 a 100.
        tv: Nombre, IP o MAC del TV. Déjalo vacío para el TV por defecto.
    """
    return _tv_result_text(tv_devices.set_volume(nivel, tv))


def silenciar_tv(tv: str = "") -> str:
    """Activa mute en el televisor registrado."""
    return _tv_result_text(tv_devices.mute(tv))


def activar_sonido_tv(tv: str = "") -> str:
    """Quita mute del televisor registrado."""
    return _tv_result_text(tv_devices.unmute(tv))


def abrir_app_tv(app: str, tv: str = "") -> str:
    """Abre una app en el TV. Usa nombres simples como youtube, netflix o disney+.

    Args:
        app: Nombre lógico de la app.
        tv: Nombre, IP o MAC del TV. Déjalo vacío para el TV por defecto.
    """
    return _tv_result_text(tv_devices.launch_app(app, tv))
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

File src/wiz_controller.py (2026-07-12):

import asyncio
import contextlib
import json
import threading
import time
from copy import deepcopy
from pathlib import Path

import config
import cuantico_profiles as profile

try:
    from pywizlight import PilotBuilder, discovery, wizlight
except Exception as e:  # pragma: no cover - depende del entorno real
    PilotBuilder = None
    discovery = None
    wizlight = None
    _IMPORT_ERROR = str(e)
else:
    _IMPORT_ERROR = ""


_STATE_PATH = Path(config.STATE_DIR) / "wiz_lights.json"
_DEFAULT_STATE = {
    "lights": [],
    "emotion_sync": {
        "enabled": False,
        "selector": "",
    },
}
_state = deepcopy(_DEFAULT_STATE)
_last_discovery: list[dict] = []
_effect_lock = threading.Lock()
_effect_thread: threading.Thread | None = None
_effect_stop: threading.Event | None = None


def _now_iso() -> str:
    return config.now_local().isoformat()


def _normalize_mac(value: str = "") -> str:
    raw = "".join(ch for ch in str(value or "").lower() if ch.isalnum())
    return raw


def _friendly_name(ip: str, mac: str = "") -> str:
    if mac:
        return f"wiz-{mac[-4:]}"
    last = ip.split(".")[-1] if ip else "wiz"
    return f"wiz-{last}"


def _migrate_entry(entry: dict) -> dict:
    item = {
        "name": str(entry.get("name") or entry.get("nombre") or "").strip(),
        "ip": str(entry.get("ip") or "").strip(),
        "mac": _normalize_mac(entry.get("mac", "")),
        "added_at": entry.get("added_at") or _now_iso(),
        "last_seen": entry.get("last_seen") or "",
        "last_state": entry.get("last_state") if isinstance(entry.get("last_state"), dict) else {},
    }
    if not item["name"]:
        item["name"] = _friendly_name(item["ip"], item["mac"])
    return item


def _dedupe_lights(entries: list[dict]) -> list[dict]:
    by_key: dict[str, dict] = {}
    ordered: list[dict] = []
    for raw in entries or []:
        item = _migrate_entry(raw if isinstance(raw, dict) else {})
        key = f"mac:{item['mac']}" if item.get("mac") else f"ip:{item.get('ip', '')}"
        if key in by_key:
            current = by_key[key]
            if item.get("ip"):
                current["ip"] = item["ip"]
            if item.get("name"):
                current["name"] = item["name"]
            if item.get("last_seen"):
                current["last_seen"] = item["last_seen"]
            if item.get("last_state"):
                current["last_state"] = item["last_state"]
            if item.get("added_at") and not current.get("added_at"):
                current["added_at"] = item["added_at"]
            continue
        by_key[key] = item
        ordered.append(item)
    return ordered


def _load_state():
    global _state
    if not _STATE_PATH.exists():
        _state = deepcopy(_DEFAULT_STATE)
        return
    try:
        raw = json.loads(_STATE_PATH.read_text(encoding="utf-8"))
        if not isinstance(raw, dict):
            raise ValueError("wiz_lights.json debe contener un objeto")
        _state = deepcopy(_DEFAULT_STATE)
        _state["lights"] = _dedupe_lights(raw.get("lights", []))
        if isinstance(raw.get("emotion_sync"), dict):
            _state["emotion_sync"].update(raw["emotion_sync"])
    except Exception:
        _state = deepcopy(_DEFAULT_STATE)


def _save_state():
    _state["lights"] = _dedupe_lights(_state.get("lights", []))
    _STATE_PATH.write_text(json.dumps(_state, ensure_ascii=False, indent=2), encoding="utf-8")


def _run(awaitable):
    loop = asyncio.new_event_loop()
    try:
        return loop.run_until_complete(awaitable)
    finally:
        loop.close()


def disponible() -> tuple[bool, str]:
    if _IMPORT_ERROR:
        return False, f"pywizlight no está disponible ({_IMPORT_ERROR})"
    return True, "wiz listo"


def _brightness_to_byte(pct: int) -> int:
    pct = max(0, min(100, int(pct)))
    return int(round((pct / 100.0) * 255))


def _brightness_from_byte(value) -> int:
    if value is None:
        return 0
    try:
        return max(0, min(100, int(round((int(value) / 255.0) * 100))))
    except Exception:
        return 0


def _match_selector(items: list[dict], selector: str) -> list[dict]:
    key = (selector or "").strip().lower()
    norm_key = _normalize_mac(key)
    if not key:
        return items
    exact = [
        item for item in items
        if key in {
            str(item.get("ip", "")).lower(),
            str(item.get("name", "")).lower(),
        }
        or (norm_key and norm_key == _normalize_mac(item.get("mac", "")))
    ]
    if exact:
        return exact
    partial = []
    for item in items:
        name = str(item.get("name", "")).lower()
        ip = str(item.get("ip", "")).lower()
        mac = _normalize_mac(item.get("mac", ""))
        if key in name or key in ip or name in key or (norm_key and norm_key in mac):
            partial.append(item)
    return partial


def _resolve_registered(selector: str = "") -> list[dict]:
    items = list(_state["lights"])
    if not items:
        return []
    return _match_selector(items, selector)


def _resolve_discovery_or_registered(selector: str) -> dict | None:
    if not selector:
        return None
    for collection in (_last_discovery, _state["lights"]):
        matched = _match_selector(list(collection), selector)
        if matched:
            return matched[0]
    return None


def _find_registered_by_ip(ip: str) -> dict | None:
    ip = str(ip or "").strip()
    for entry in _state["lights"]:
        if entry.get("ip") == ip:
            return entry
    return None


def _find_registered_by_mac(mac: str) -> dict | None:
    norm_mac = _normalize_mac(mac)
    if not norm_mac:
        return None
    for entry in _state["lights"]:
        if _normalize_mac(entry.get("mac", "")) == norm_mac:
            return entry
    return None


async def _discover_async() -> list:
    finder = getattr(discovery, "discover_lights", None) or getattr(discovery, "find_wizlights", None)
    if finder is None:
        raise RuntimeError("la versión instalada de pywizlight no soporta discovery")
    kwargs = {}
    if getattr(config, "WIZ_BROADCAST_SPACE", ""):
        kwargs["broadcast_space"] = config.WIZ_BROADCAST_SPACE
    try:
        if kwargs:
            return await finder(**kwargs)
        return await finder()
    except TypeError:
        if kwargs:
            return await finder(discovery, **kwargs)
        return await finder(discovery)
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

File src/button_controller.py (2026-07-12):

import threading
import time
from typing import Callable

import config
import luces

try:
    import RPi.GPIO as GPIO
except Exception:  # pragma: no cover - en desarrollo local puede no existir GPIO
    GPIO = None


BUTTON_SINGLE_CLICK = "BUTTON_SINGLE_CLICK"
BUTTON_DOUBLE_CLICK = "BUTTON_DOUBLE_CLICK"
BUTTON_TRIPLE_CLICK = "BUTTON_TRIPLE_CLICK"
BUTTON_LONG_PRESS = "BUTTON_LONG_PRESS"
BUTTON_QUAD_CLICK = "BUTTON_QUAD_CLICK"

_EVENT_NAMES = {
    1: BUTTON_SINGLE_CLICK,
    2: BUTTON_DOUBLE_CLICK,
    3: BUTTON_TRIPLE_CLICK,
    4: BUTTON_QUAD_CLICK,
}

_BUTTON_FEEDBACK_COLORS = {
    1: (0, 255, 70),
    2: (255, 140, 0),
    3: (170, 80, 255),
    4: (80, 180, 255),
}


class ButtonController:
    def __init__(
        self,
        pin_bcm: int,
        debounce_ms: int = 50,
        group_window_ms: int = 450,
    ):
        self.pin_bcm = int(pin_bcm)
        self.debounce_ms = int(debounce_ms)
        self.group_window_ms = int(group_window_ms)
        self._callbacks: list[Callable[[str, dict], None]] = []
        self._lock = threading.RLock()
        self._click_count = 0
        self._timer: threading.Timer | None = None
        self._running = False
        self._poll_thread: threading.Thread | None = None
        self._using_polling = False
        self._last_press_ts = 0.0

    def register_callback(self, callback: Callable[[str, dict], None]):
        with self._lock:
            self._callbacks.append(callback)

    def start(self) -> bool:
        if GPIO is None:
            return False
        with self._lock:
            if self._running:
                return True
            GPIO.setwarnings(False)
            GPIO.setmode(GPIO.BCM)
            try:
                GPIO.remove_event_detect(self.pin_bcm)
            except Exception:
                pass
            try:
                GPIO.cleanup(self.pin_bcm)
            except Exception:
                pass
            GPIO.setup(self.pin_bcm, GPIO.IN, pull_up_down=GPIO.PUD_OFF)
            self._running = True
            self._using_polling = False
            self._last_press_ts = 0.0
            try:
                GPIO.add_event_detect(
                    self.pin_bcm,
                    GPIO.FALLING,
                    callback=self._gpio_falling_edge,
                    bouncetime=self.debounce_ms,
                )
                print(f"🔘 Botón GPIO {self.pin_bcm}: interrupción activada")
            except RuntimeError as e:
                # En algunas Raspberry o tras reinicios bruscos RPi.GPIO puede
                # rechazar edge detection aunque el pin esté bien cableado.
                # Caemos a polling para no tumbar todo Cuántico.
                print(f"⚠️ Botón GPIO {self.pin_bcm}: falló add_event_detect ({e}); uso polling.")
                self._using_polling = True
                self._poll_thread = threading.Thread(target=self._poll_loop, daemon=True, name="button-poll")
                self._poll_thread.start()
        return True

    def close(self):
        with self._lock:
            timer = self._timer
            self._timer = None
            self._click_count = 0
            self._running = False
            self._using_polling = False
            poll_thread = self._poll_thread
            self._poll_thread = None
        if timer:
            timer.cancel()
        if GPIO is not None:
            try:
                GPIO.remove_event_detect(self.pin_bcm)
            except Exception:
                pass
            try:
                GPIO.cleanup(self.pin_bcm)
            except Exception:
                pass
        if poll_thread and poll_thread.is_alive():
            poll_thread.join(timeout=0.3)
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

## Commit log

2026-06-23 implementacion de logs
2026-06-25 reparacion de cuelgue
2026-07-03 antes de corregir inicializar
2026-07-04 cambios antes de aplicar memoria nueva
2026-07-10 mejora de alarmas musicales o tareas programadas y recuerrencia
2026-07-12 implemento boton cotrreccion final de musica play on / off
2026-09-28 mejora de comandos tv
